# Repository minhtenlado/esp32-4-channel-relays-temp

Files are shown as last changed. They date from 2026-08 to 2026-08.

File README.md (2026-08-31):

<div align="center">

# ⚡ Mạch Điều Khiển 4 Relay Cách Ly Quang Dùng ESP32 (KiCad)

Dự án thiết kế phần cứng mã nguồn mở **Mạch Điều Khiển 4 Kênh Relay sử dụng vi điều khiển ESP32-WROOM-32**, thiết kế trên phần mềm **KiCad**. Mạch tích hợp cách ly quang toàn phần (Optocoupler), cổng nạp USB Type-C tự động reset (Auto-Download), bảo vệ chống tĩnh điện ESD, cầu chì tự phục hồi PTC và rãnh cách ly an toàn điện áp cao (Creepage Slots) chuyên dụng cho nhà thông minh (Smart Home) và tự động hóa công nghiệp (IoT).







<br/>

[📖 English Version](README_EN.md) • [📑 Xem Sơ Đồ Nguyên Lý PDF](schematic.pdf) • [📊 Danh Mục Linh Kiện (BOM)](docs/BOM.md) • [📌 Sơ Đồ Chân (Pinout)](docs/PINOUT.md)

<br/>

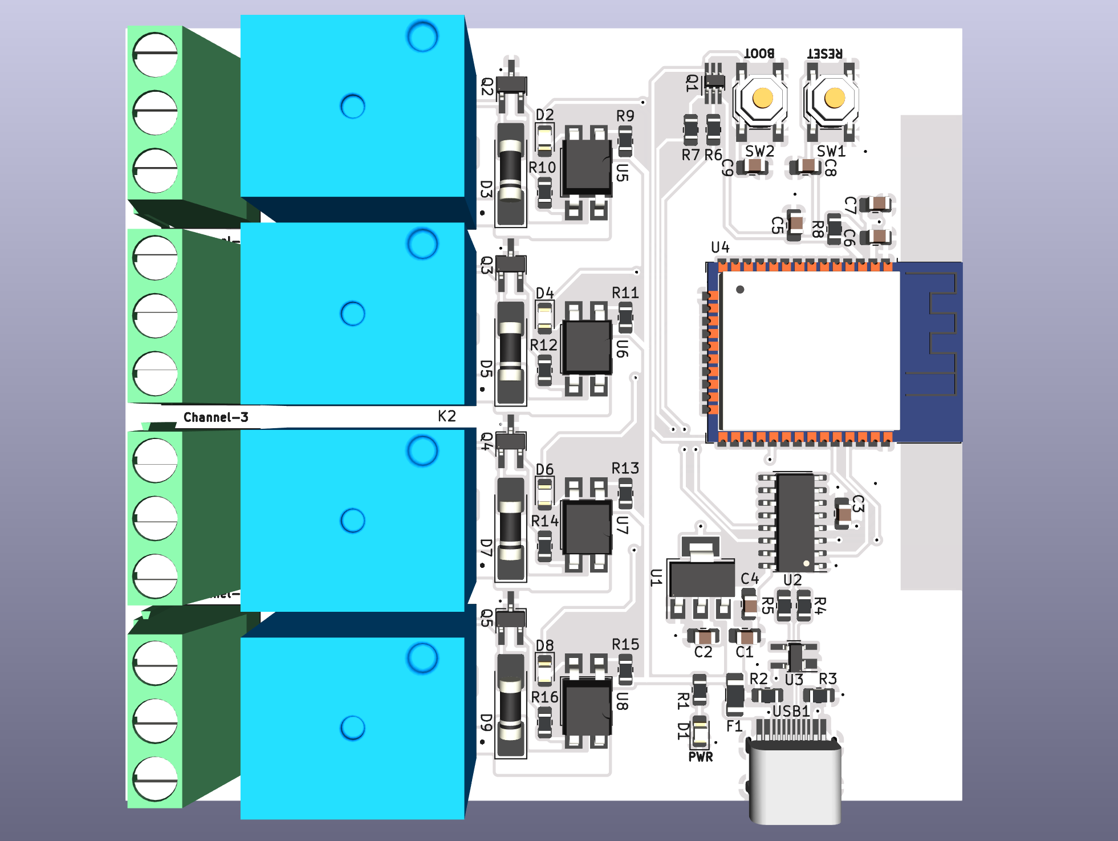
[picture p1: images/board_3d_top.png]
Phối cảnh 3D Mạch Điều Khiển 4 Relay ESP32


</div>

---

## 🌟 Điểm Nổi Bật Của Thiết Kế

- 🧠 **Vi điều khiển lõi kép ESP32**: ESP32-WROOM-32 tích hợp kết nối Wi-Fi 2.4 GHz và Bluetooth LE 4.2 tốc độ cao.
- 🔌 **4 Kênh Relay độc lập**: Sử dụng Relay Songle SRD-05VDC-SL-C cho khả năng đóng cắt dòng tải lên đến **10A @ 250VAC / 10A @ 30VDC**.
- 🛡️ **Cách ly quang an toàn (Galvanic Opto-Isolation)**: Sử dụng 4 Optocoupler PC817 cách ly hoàn toàn khối vi điều khiển 3.3V với khối cuộn hút Relay 5V, chống nhiễu xung ngược khi đóng ngắt.
- ⚡ **Cổng giao tiếp USB Type-C hiện đại**: Cổng Type-C (HRO-TYPE-C-31-M-12) vừa cấp nguồn 5V vừa nạp code trực tiếp từ máy tính.
- 🔄 **Mạch tự động nạp & reset (Auto-Download)**: Tích hợp chip chuyển đổi USB-UART CH340C cùng cặp transistor MBT3904DW1 điều khiển chân `EN` và `IO0` (tự động vào chế độ nạp không cần nhấn nút thủ công).
- 🔒 **Hệ thống bảo vệ phần cứng đa lớp**:
  - Cầu chì tự phục hồi PTC 500mA (`F1`) bảo vệ quá dòng cổng USB.
  - Mảng Diode TVS PRTR5V0U2X (`U3`) triệt tiêu xung tĩnh điện ESD trên đường tín hiệu USB D+/D-.
  - Diode dập xung ngược 1N4007 (`D3, D5, D7, D9`) bảo vệ transistor khi ngắt cuộn dây relay.
  - Phay rãnh cách ly điện áp cao (Isolation Creepage Slots) giữa tiếp điểm Relay và mạch điều khiển.
- 💡 **Đèn LED hiển thị trực quan**:
  - 1 LED Vàng báo nguồn 3.3V (`D1`).
  - 4 LED Đỏ báo trạng thái kích hoạt của từng Relay (`D2, D4, D6, D8`).
- 📶 **Thiết kế anten RF tối ưu**: Khu vực Anten PCB của ESP32 được bố trí nhô ra ngoài với vùng cấm đi dây (Keep-out Zone) để tăng tối đa khoảng cách thu phát sóng Wi-Fi.

---

## 📸 Hình Ảnh Phối Cảnh & Layout PCB

<div align="center">
  <table>
    <tr>
      <td align="center"><b>Phối cảnh 3D Mặt Trước (Top View)</b></td>
      <td align="center"><b>Phối cảnh 3D Mặt Sau (Bottom View)</b></td>
    </tr>
    <tr>
      <td>Mặt trước 3D</td>
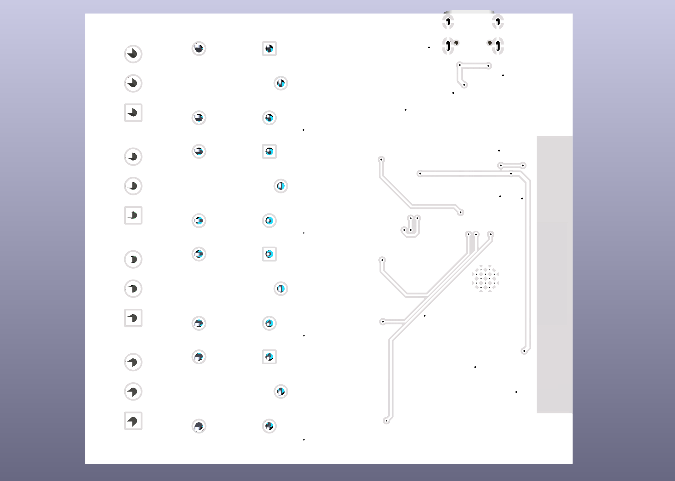
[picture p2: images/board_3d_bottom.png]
Mặt sau 3D
      <td></td>
    </tr>
    <tr>
      <td colspan="2" align="center"><b>Bản Vẽ Thiết Kế Layout 2D (KiCad PCB)</b></td>
    </tr>
    <tr>
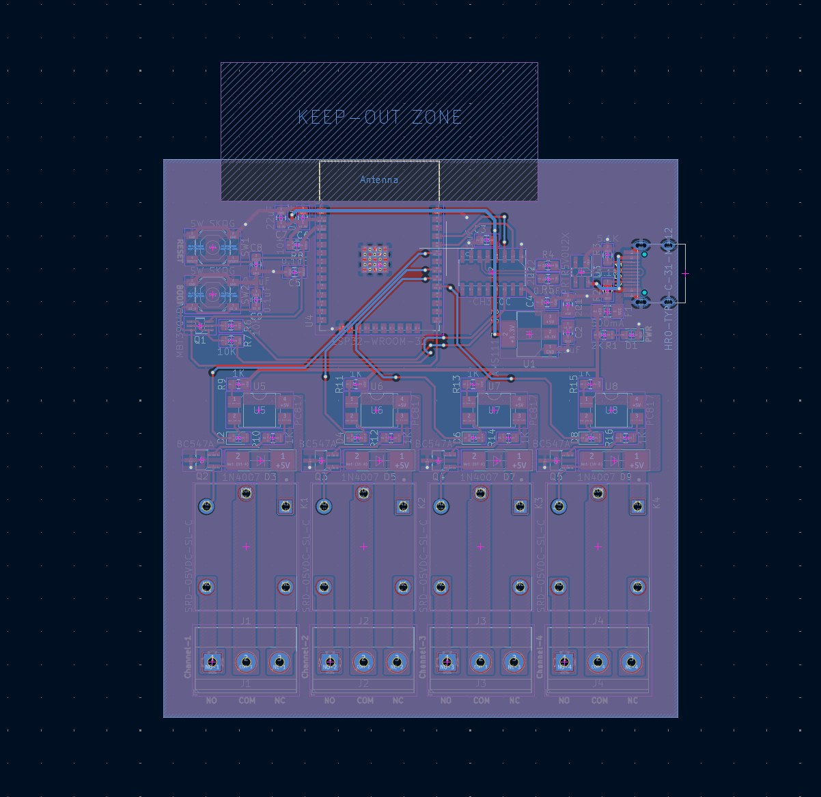
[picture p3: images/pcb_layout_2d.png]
PCB Layout 2D
      <td colspan="2" align="center"></td>
    </tr>
  </table>
</div>

---

## 📋 Thông Số Kỹ Thuật Chi Tiết

| Thông số | Giá trị chi tiết |
| :--- | :--- |
| **Vi điều khiển chính** | ESP32-WROOM-32 (Xtensa Dual-Core 32-bit LX6, tần số tối đa 240 MHz) |
| **Nguồn cấp đầu vào** | 5V DC qua cổng USB Type-C |
| **Điện áp hoạt động Logic** | 3.3V DC (Hạ áp qua IC AMS1117-3.3V dòng tối đa 1A) |
| **Số kênh Relay** | 4 Kênh độc lập (Tiếp điểm SPDT: NO - Thường mở, COM - Chung, NC - Thường đóng) |
| **Loại Relay** | Songle SRD-05VDC-SL-C (Cuộn hút 5V DC) |
| **Công suất tiếp điểm (AC)**| 10A 250VAC / 10A 125VAC |
| **Công suất tiếp điểm (DC)**| 10A 30VDC / 10A 28VDC |
| **Cổng kết nối tải** | 4 Domino (Terminal Block) 3 chân, bước chân chuẩn 5.08mm |
| **Cơ chế cách ly** | Optocoupler quang PC817 + Rãnh cách ly phay cơ khí trên mạch |
| **Chip nạp USB-UART** | CH340C (Tích hợp sẵn thạch anh nội dao động) |
| **Nền tảng lập trình hỗ trợ** | Arduino IDE, PlatformIO, ESP-IDF, ESPHome (Home Assistant), Tasmota |

---

## 📌 Sơ Đồ Chân (Pinout & GPIO Mapping)

| Kênh chức năng | Chân ESP32 | Mức kích hoạt | Opto cách ly | Transistor kích | LED Trạng thái | Cổng Domino ra tải |
| :--- | :---: | :---: | :---: | :---: | :---: | :--- |
| **Relay 1** | `GPIO 21` | Mức CAO (`HIGH`) | U5 (PC817) | Q2 (BC547A) | `D2` (LED Đỏ) | **J1** (NO, COM, NC) |
| **Relay 2** | `GPIO 19` | Mức CAO (`HIGH`) | U6 (PC817) | Q3 (BC547A) | `D4` (LED Đỏ) | **J2** (NO, COM, NC) |
| **Relay 3** | `GPIO 18` | Mức CAO (`HIGH`) | U7 (PC817) | Q4 (BC547A) | `D6` (LED Đỏ) | **J3** (NO, COM, NC) |
| **Relay 4** | `GPIO 5`  | Mức CAO (`HIGH`) | U8 (PC817) | Q5 (BC547A) | `D8` (LED Đỏ) | **J4** (NO, COM, NC) |
| **UART RX**  | `GPIO 3`  | - | - | - | Chân TX CH340C | Cổng nạp USB Type-C |
| **UART TX**  | `GPIO 1`  | - | - | - | Chân RX CH340C | Cổng nạp USB Type-C |
| **Nút BOOT** | `GPIO 0`  | Mức THẤP (`LOW`) | - | - | Nút nhấn `SW2` | Vào chế độ nạp thủ công |
| **Nút RESET**| `EN` | Mức THẤP (`LOW`) | - | - | Nút nhấn `SW1` | Reset phần cứng |
| **LED Nguồn**| `+3.3V` | Sáng liên tục | - | - | `D1` (LED Vàng) | Báo nguồn 3.3V ổn định |

👉 Xem hướng dẫn phân tích phần cứng và chân strapping chi tiết tại: [docs/PINOUT.md](docs/PINOUT.md).

---

## 🗂️ Cấu Trúc Thư Mục Dự Án

```text
.
├── esp32-4-channel-relays.kicad_pro   # File Project KiCad (v7 / v8 / v10)
├── esp32-4-channel-relays.kicad_sch   # File Sơ đồ nguyên lý (Schematic)
├── esp32-4-channel-relays.kicad_pcb   # File Thiết kế mạch in (PCB Layout)
├── schematic.pdf                      # Bản xuất sơ đồ nguyên lý định dạng PDF
├── images/                            # Ảnh render 3D và sơ đồ layout PCB
│   ├── board_3d_top.png               # Phối cảnh 3D mặt trước
│   ├── board_3d_bottom.png            # Phối cảnh 3D mặt sau
│   └── pcb_layout_2d.png              # Bản vẽ layout PCB 2D
├── lib/                               # Thư viện linh kiện KiCad riêng của dự án
│   ├── 3dmodel/                       # Mô hình 3D CAD (.step, .wrl)
│   ├── footprint/                     # Thư viện Footprint chân linh kiện (.kicad_mod)
│   └── symbol/                        # Thư viện Symbol ký hiệu nguyên lý (.kicad_sym)
├── docs/                              # Tài liệu kỹ thuật dự án
│   ├── BOM.md                         # Bảng danh mục linh kiện (Markdown)
│   ├── BOM.csv                        # Danh mục linh kiện (File CSV)
│   └── PINOUT.md                      # Bảng tra cứu sơ đồ chân phần cứng
├── firmware/                          # Mã nguồn mẫu sẵn sàng nạp
│   ├── arduino/esp32_4ch_relay_web/   # Code Arduino Web Server + REST API điều khiển Relay
│   └── esphome/esp32_4ch_relay.yaml   # Cấu hình ESPHome nạp vào Home Assistant
├── .github/                           # GitHub Actions CI kiểm tra file & mẫu Issue
├── .gitignore                         # Bộ lọc file rác, file tạm của KiCad
├── CONTRIBUTING.md                    # Hướng dẫn đóng góp phát triển dự án
├── LICENSE                            # Giấy phép mã nguồn mở CERN-OHL-P v2 & MIT
├── README_EN.md                       # Tài liệu tiếng Anh (English documentation)
└── README.md                          # Tài liệu hướng dẫn chính (Tiếng Việt)
```

---

## 🚀 Hướng Dẫn Nạp Firmware & Sử Dụng

### 1. Điều khiển qua Web & Serial bằng Arduino IDE
Mã nguồn mẫu hoàn chỉnh có sẵn tại thư mục [`firmware/arduino/esp32_4ch_relay_web/`](firmware/arduino/esp32_4ch_relay_web/esp32_4ch_relay_web.ino).

1. Cài đặt **Arduino IDE** và cài board **ESP32 by Espressif**.
2. Mở file `esp32_4ch_relay_web.ino`.
3. Điền thông tin Wi-Fi nhà bạn:
   ```cpp
   const char* WIFI_SSID = "TEN_WIFI_CUA_BAN";
   const char* WIFI_PASS = "MAT_KHAU_WIFI";
   ```
4. Cắm cáp USB Type-C từ máy tính vào mạch, chọn cổng COM và bấm **Upload** (Mạch có tính năng tự động nạp code không cần giữ nút BOOT).
5. Mở trình duyệt web truy cập vào: `http://esp32-relay.local` hoặc địa chỉ IP hiển thị trên Serial Monitor để điều khiển bật/tắt 4 relay.

### 2. Tích hợp trực tiếp vào Home Assistant qua ESPHome
Dự án đã chuẩn bị sẵn file cấu hình [`firmware/esphome/esp32_4ch_relay.yaml`](firmware/esphome/esp32_4ch_relay.yaml).

1. Cài đặt [ESPHome](https://esphome.io/) trên máy tính hoặc Add-on trong Home Assistant.
2. Nạp file cấu hình qua USB bằng lệnh:
   ```bash
   esphome run firmware/esphome/esp32_4ch_relay.yaml
   ```
3. Sau khi nạp xong, Home Assistant sẽ tự động nhận diện thiết bị và tạo sẵn 4 công tắc tương ứng với 4 kênh relay.

---

## ⚠️ Cảnh Báo An Toàn Điện Áp Cao (220V AC)

> [!WARNING]
> **CẢNH BÁO AN TOÀN ĐIỆN NGUY HIỂM**: Đóng cắt điện lưới xoay chiều 220V AC tiềm ẩn nguy cơ giật điện và hỏa hoạn nghiêm trọng.
> - Luôn ngắt toàn bộ nguồn điện trước khi đấu nối dây điện vào cọc Domino (Terminal Block).
> - Khi đóng cắt tải điện 220V, bắt buộc phải đặt mạch trong hộp bảo vệ cách điện (nhựa chống cháy, in 3D kín).
> - Đảm bảo dòng điện tải thực tế không vượt quá định mức của tiếp điểm Relay và đường mạch đồng.

---

## 📦 Danh Mục Linh Kiện (BOM)

Toàn bộ thông tin chi tiết về linh kiện (Package SMD 0805 dễ hàn tay, chân cắm THT, mã IC):
- 📄 [Xem Bảng Tra Linh Kiện BOM (Markdown)](docs/BOM.md)
- 📊 [Tải File Excel/CSV BOM (docs/BOM.csv)](docs/BOM.csv)
- 📑 [Xem Bản Vẽ Sơ Đồ Nguyên Lý PDF](schematic.pdf)

---

## 📄 Bản Quyền & Tác Giả

- **Thiết kế phần cứng**: Cấp phép theo chuẩn phần cứng mở **[CERN-OHL-P v2](https://cern-ohl.web.cern.ch/)** (CERN Open Hardware Licence Version 2 - Permissive).
- **Mã nguồn phần mềm & Tài liệu**: Cấp phép theo chuẩn **[MIT License](LICENSE)**.
- **Tác giả thiết kế**: **Phan Huỳnh Văn Đô** (`2023 - 2026`).

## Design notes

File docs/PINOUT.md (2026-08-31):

# Sơ Đồ Chân (Pinout) & Cấu Trúc Phần Cứng ESP32 4-Channel Relays

## 1. Bảng Ánh Xạ Chân Điều Khiển 4 Kênh Relay

Vi điều khiển ESP32 điều khiển từng kênh relay thông qua tầng cách ly quang Optocoupler và transistor đệm dòng.

| Kênh | Chân ESP32 | Optocoupler | Transistor kích | LED Trạng thái | Diode dập xung | Cổng kết nối (Domino) | Mức kích hoạt |
| :--- | :--- | :--- | :--- | :--- | :--- | :--- | :--- |
| **Relay 1** | `GPIO 21` | U5 (PC817) | Q2 (BC547A) | D2 (Đỏ) | D3 (1N4007) | J1 (NO, COM, NC) | Mức CAO (`HIGH`) |
| **Relay 2** | `GPIO 19` | U6 (PC817) | Q3 (BC547A) | D4 (Đỏ) | D5 (1N4007) | J2 (NO, COM, NC) | Mức CAO (`HIGH`) |
| **Relay 3** | `GPIO 18` | U7 (PC817) | Q4 (BC547A) | D6 (Đỏ) | D7 (1N4007) | J3 (NO, COM, NC) | Mức CAO (`HIGH`) |
| **Relay 4** | `GPIO 5`  | U8 (PC817) | Q5 (BC547A) | D8 (Đỏ) | D9 (1N4007) | J4 (NO, COM, NC) | Mức CAO (`HIGH`) |

*Ghi chú*: Mạch được thiết kế kích ở **Mức CAO** (Xuất tín hiệu `HIGH` sẽ làm sáng LED bên trong Optocoupler, kích dẫn Transistor BC547A đóng cuộn hút Relay và làm sáng LED đỏ báo hiệu).

---

## 2. Ý Nghĩa Các Tiếp Điểm Trên Cọc Đấu Nối Domino (5.08mm)

Mỗi kênh Relay đi ra 1 cọc domino 3 chân có nhãn:
- **NO (Normally Open - Thường mở)**: Tiếp điểm hở mạch khi relay chưa được kích hoạt, đóng mạch khi relay có điện.
- **COM (Common - Chân chung)**: Chân chung để đấu nguồn điện cấp cho tải.
- **NC (Normally Closed - Thường đóng)**: Tiếp điểm đóng mạch khi relay chưa được kích hoạt, hở mạch khi relay có điện.

---

## 3. Kiến Trúc Cung Cấp Nguồn Điện

| Đường nguồn | Nguồn cấp vào | IC điều chỉnh | Dòng tối đa | Mục đích sử dụng |
| :--- | :--- | :--- | :--- | :--- |
| **+5V (VBUS)** | Cổng USB Type-C | Qua cầu chì F1 (500mA PTC) | ~500mA - 1A | Cấp nguồn cuộn hút 4 Relay (SRD-05VDC-SL-C) |
| **+3.3V** | Từ đường 5V | IC Hạ áp AMS1117-3.3 (U1) | 1A | Cấp nguồn cho ESP32-WROOM-32, IC nạp CH340C |
| **GND** | Cổng USB Type-C | Mặt phẳng GND chung | - | Mass toàn hệ thống |

---

## 4. Mạch Tự Động Nạp (Auto-Download) & Nút Nhấn

| Tín hiệu / Linh kiện | Chân ESP32 | Chức năng |
| :--- | :--- | :--- |
| **TXD (CH340C TX)** | `GPIO 3` (RXD0) | Nhận dữ liệu UART0 từ máy tính vào ESP32 |
| **RXD (CH340C RX)** | `GPIO 1` (TXD0) | Truyền dữ liệu UART0 từ ESP32 lên máy tính |
| **DTR / RTS** | `EN` / `GPIO 0` | Tín hiệu tự động reset / vào bootloader qua Q1 (MBT3904DW1) |
| **Nút SW1 (RESET)** | `EN` (CHIP_PU) | Nút reset phần cứng (Mức THẤP, có trở kéo 10k và tụ lọc nhiễu 0.1uF) |
| **Nút SW2 (BOOT)** | `GPIO 0` | Nút kích hoạt chế độ Bootloader thủ công (Mức THẤP, có trở kéo 10k) |

---

## 5. Bảng Chân Cấu Hình Khởi Động ESP32 (Strapping Pins)

| Chân GPIO | Trạng thái mặc định | Kết nối trên mạch | Lưu ý khi lập trình |
| :--- | :--- | :--- | :--- |
| `GPIO 0` | Kéo lên (+3.3V qua 10k) | Nối nút SW2 / Mạch nạp Q1 | Kéo xuống LOW lúc khởi động để vào chế độ nạp ROM |
| `GPIO 2` | Kéo xuống LOW nội | Bỏ trống | Giữ ở mức LOW hoặc thả nổi khi nạp firmware |
| `GPIO 5` | Mức CAO lúc boot | **Kích Relay 4** | Có xung phát ra lúc ESP32 vừa bật nguồn, hoạt động bình thường |
| `GPIO 12` | Kéo xuống LOW (MTDI) | Bỏ trống | Chọn điện áp Flash 3.3V |
| `GPIO 15` | Mức CAO (MTDO) | Bỏ trống | Bật/tắt chế độ in log bootloader qua UART |

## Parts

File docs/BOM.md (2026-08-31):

# Bảng Danh Mục Linh Kiện (BOM) - Mạch Điều Khiển 4 Relay ESP32

Danh mục linh kiện đầy đủ cho mạch điều khiển 4 Relay cách ly quang ESP32-WROOM-32.

| STT | Số lượng | Ký hiệu (Designator) | Giá trị / Tên linh kiện | Đóng gói (Footprint) | Chức năng / Mô tả chi tiết |
| :---: | :---: | :--- | :--- | :--- | :--- |
| 1 | 1 | `U4` | ESP32-WROOM-32 | Module SMD | Vi điều khiển 32-bit Wi-Fi & Bluetooth Dual-Core |
| 2 | 4 | `K1, K2, K3, K4` | SRD-05VDC-SL-C | THT Relay | Relay 5VDC SPDT (Đóng ngắt 10A 250VAC / 10A 30VDC) |
| 3 | 4 | `U5, U6, U7, U8` | PC817 | SMDIP-4 | Optocoupler cách ly quang bảo vệ vi điều khiển |
| 4 | 4 | `Q2, Q3, Q4, Q5` | BC547A / NPN | SOT-23 | Transistor NPN đóng ngắt cuộn hút 5V của Relay |
| 5 | 4 | `D3, D5, D7, D9` | 1N4007 | MELF / DO-213AB | Diode dập xung điện áp ngược khi ngắt cuộn dây (1A 1000V) |
| 6 | 4 | `D2, D4, D6, D8` | LED Đỏ | 0805 SMD | Đèn LED hiển thị trạng thái kích hoạt Kênh 1 - 4 |
| 7 | 1 | `D1` | LED Vàng | 0805 SMD | Đèn LED báo nguồn 3.3V của mạch |
| 8 | 4 | `J1, J2, J3, J4` | Domino 3 Chân (Terminal) | Bước chân 5.08mm | Cọc đấu nối ra tải điện (NO - Thường mở, COM - Chung, NC - Thường đóng) |
| 9 | 1 | `USB1` | Type-C 16-Pin | HRO-TYPE-C-31-M-12 | Cổng USB Type-C cấp nguồn 5V và nạp dữ liệu |
| 10 | 1 | `U2` | CH340C | SOIC-16 | IC chuyển đổi USB sang UART tích hợp sẵn dao động thạch anh |
| 11 | 1 | `Q1` | MBT3904DW1 | SOT-363 / SC-70-6 | Cặp transistor NPN kép trong mạch tự động nạp & reset |
| 12 | 1 | `U1` | AMS1117-3.3 | SOT-223-3 | IC ổn áp tuyến tính 3.3V 1A cấp nguồn cho ESP32 |
| 13 | 1 | `U3` | PRTR5V0U2X | SOT-143 | Diode TVS chống tĩnh điện ESD cho 2 đường dữ liệu USB |
| 14 | 1 | `F1` | Cầu chì PTC 500mA | 1206 SMD | Cầu chì tự phục hồi chống quá dòng cổng USB |
| 15 | 2 | `SW1, SW2` | Nút nhấn nhả (Tactile) | SKQG SMD 6x6mm | Nút bấm RESET (SW1) và nút BOOT (SW2) |
| 16 | 8 | `R9, R10, R11, R12, R13, R14, R15, R16` | 1kΩ 1% | 0805 SMD | Điện trở hạn dòng cho LED opto và phân cực cực B transistor |
| 17 | 3 | `R6, R7, R8` | 10kΩ 1% | 0805 SMD | Điện trở kéo lên (Pull-up) cho chân EN, IO0 và BOOT |
| 18 | 2 | `R2, R3` | 5.1kΩ 1% | 0805 SMD | Điện trở kéo xuống cấu hình nhận diện cổng USB Type-C (CC1, CC2) |
| 19 | 2 | `R4, R5` | 22Ω 1% | 0805 SMD | Điện trở phối hợp trở kháng trên đường dữ liệu USB D+ / D- |
| 20 | 1 | `R1` | 2kΩ 1% | 0805 SMD | Điện trở hạn dòng cho đèn LED báo nguồn D1 |
| 21 | 3 | `C1, C2, C7` | 22µF 16V | 0805 SMD | Tụ gốm lọc nguồn chính đường 5V và 3.3V |
| 22 | 6 | `C3, C4, C5, C6, C8, C9` | 0.1µF (100nF) 50V | 0805 SMD | Tụ gốm lọc nhiễu cao tần (Decoupling) |

> **Ghi chú**: Các điện trở và tụ điện SMD sử dụng chuẩn chân **0805** giúp việc hàn thủ công bằng mỏ hàn tay dễ dàng và đẹp mắt.

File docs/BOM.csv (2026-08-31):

Item | Qty | Reference | Value | Footprint | Description
1 | 1 | U4 | ESP32-WROOM-32 | Module SMD | Wi-Fi & Bluetooth Dual-Core MCU Module
2 | 4 | K1, K2, K3, K4 | SRD-05VDC-SL-C | THT Relay | 5VDC SPDT Relay (10A 250VAC / 10A 30VDC)
3 | 4 | U5, U6, U7, U8 | PC817 | SMDIP-4 | Optocoupler Phototransistor Galvanic Isolator
4 | 4 | Q2, Q3, Q4, Q5 | BC547A / NPN | SOT-23 | NPN General Purpose Transistor (Relay Coil Driver)
5 | 4 | D3, D5, D7, D9 | 1N4007 | MELF / DO-213AB | 1A 1000V General Purpose Flyback Diode
6 | 4 | D2, D4, D6, D8 | RED LED | 0805 SMD | Relay Channel 1-4 Active Status Indicator
7 | 1 | D1 | YELLOW LED | 0805 SMD | 3.3V Power Rail Indicator
8 | 4 | J1, J2, J3, J4 | Screw Terminal 3-Pin | 5.08mm Pitch | Screw Terminal (NO, COM, NC Contacts)
9 | 1 | USB1 | Type-C 16-Pin | HRO-TYPE-C-31-M-12 | USB Type-C Receptacle 5V Power & Data
10 | 1 | U2 | CH340C | SOIC-16 | USB to Serial UART Interface with Built-in Oscillator
11 | 1 | Q1 | MBT3904DW1 | SOT-363 / SC-70-6 | Dual NPN Transistor Auto-Reset & Download Circuit
12 | 1 | U1 | AMS1117-3.3 | SOT-223-3 | 3.3V 1A Low Dropout Linear Voltage Regulator
13 | 1 | U3 | PRTR5V0U2X | SOT-143 | Ultra-low Capacitance TVS Diode ESD Protection
14 | 1 | F1 | 500mA PTC | 1206 SMD | Resettable Polyfuse Overcurrent Protection
15 | 2 | SW1, SW2 | Tactile Button | SKQG / 6x6mm SMD | Tactile Switches (RESET / BOOT)
16 | 8 | R9, R10, R11, R12, R13, R14, R15, R16 | 1kΩ 1% | 0805 SMD | Optocoupler LED Current Limiting & Base Drive Resistors
17 | 3 | R6, R7, R8 | 10kΩ 1% | 0805 SMD | Pull-Up Resistors (EN / IO0 / BOOT)
18 | 2 | R2, R3 | 5.1kΩ 1% | 0805 SMD | USB Type-C CC1 / CC2 Pull-Down Resistors
19 | 2 | R4, R5 | 22Ω 1% | 0805 SMD | USB D+ / D- Series Termination Resistors
20 | 1 | R1 | 2kΩ 1% | 0805 SMD | Power LED Current Limiting Resistor
21 | 3 | C1, C2, C7 | 22µF 16V | 0805 SMD | Bulk Filtering Capacitors (5V / 3.3V rails)
22 | 6 | C3, C4, C5, C6, C8, C9 | 0.1µF (100nF) 50V | 0805 SMD | Decoupling Ceramic Capacitors

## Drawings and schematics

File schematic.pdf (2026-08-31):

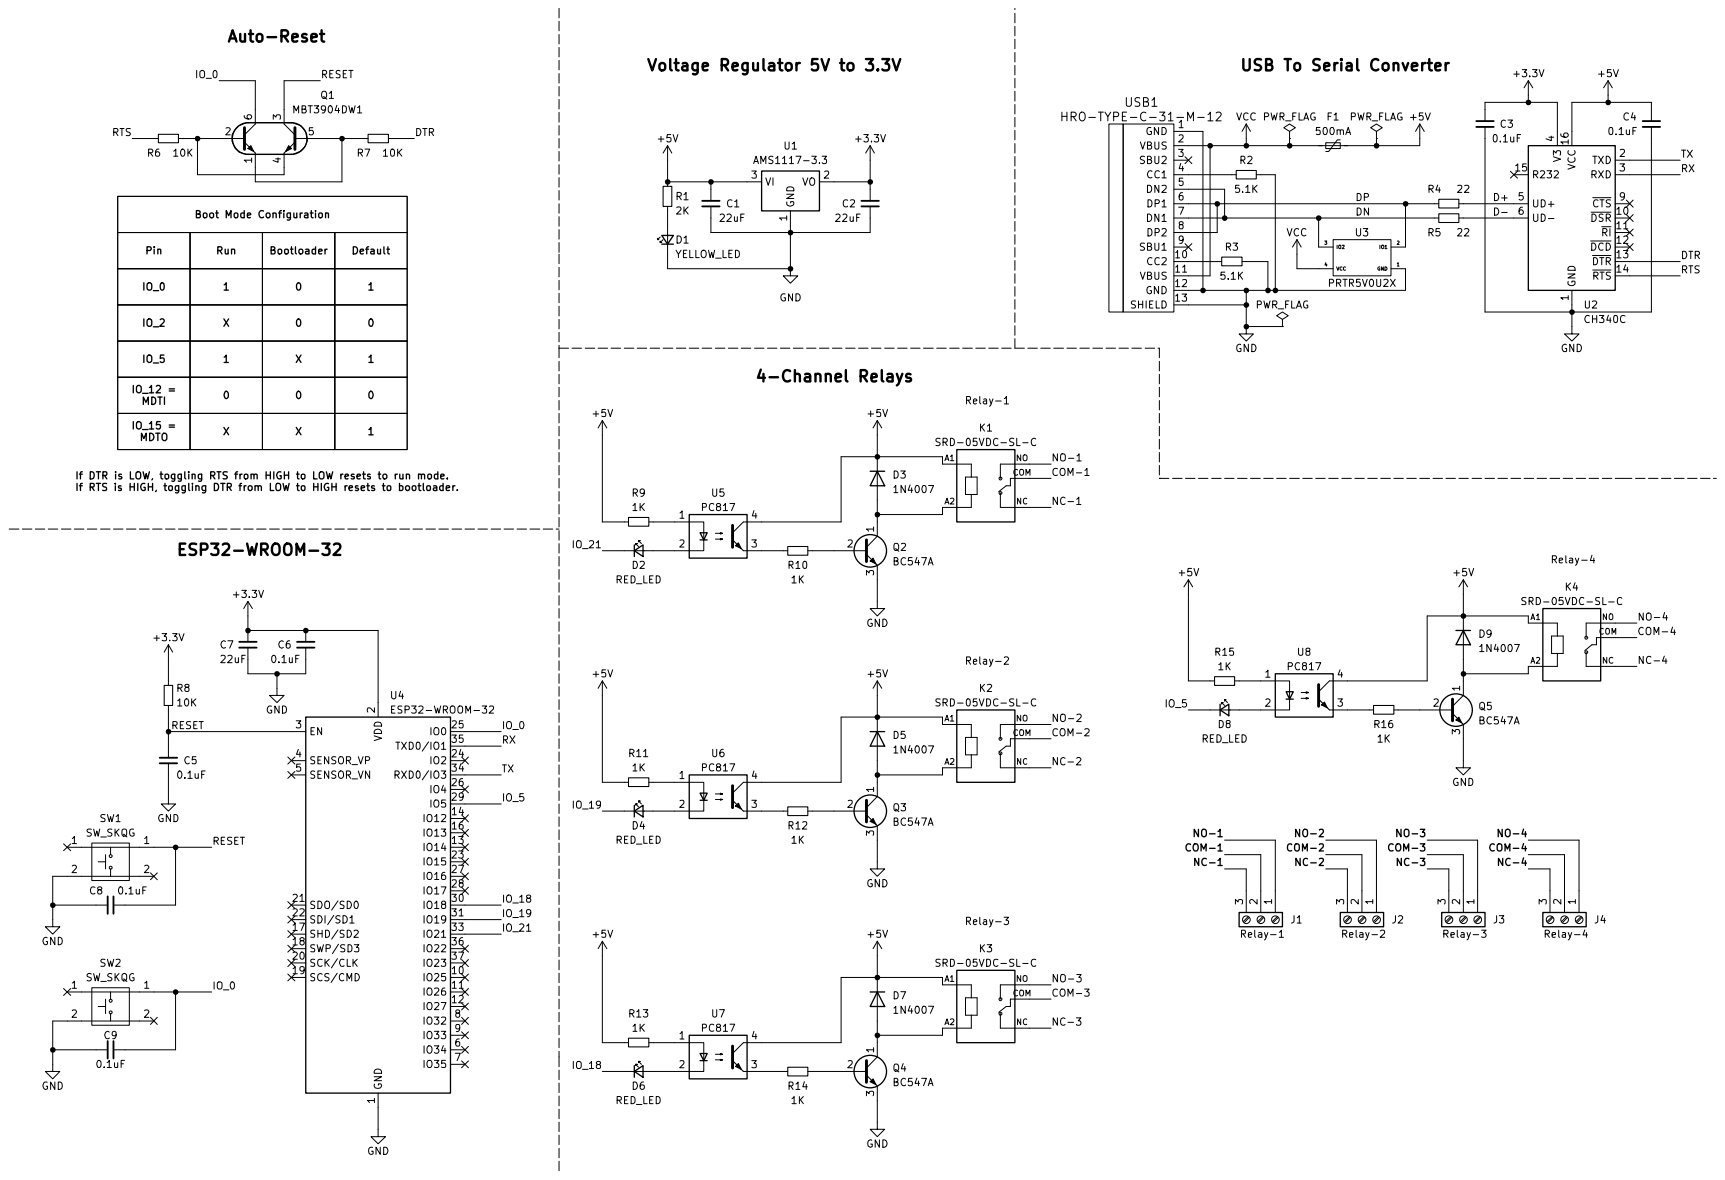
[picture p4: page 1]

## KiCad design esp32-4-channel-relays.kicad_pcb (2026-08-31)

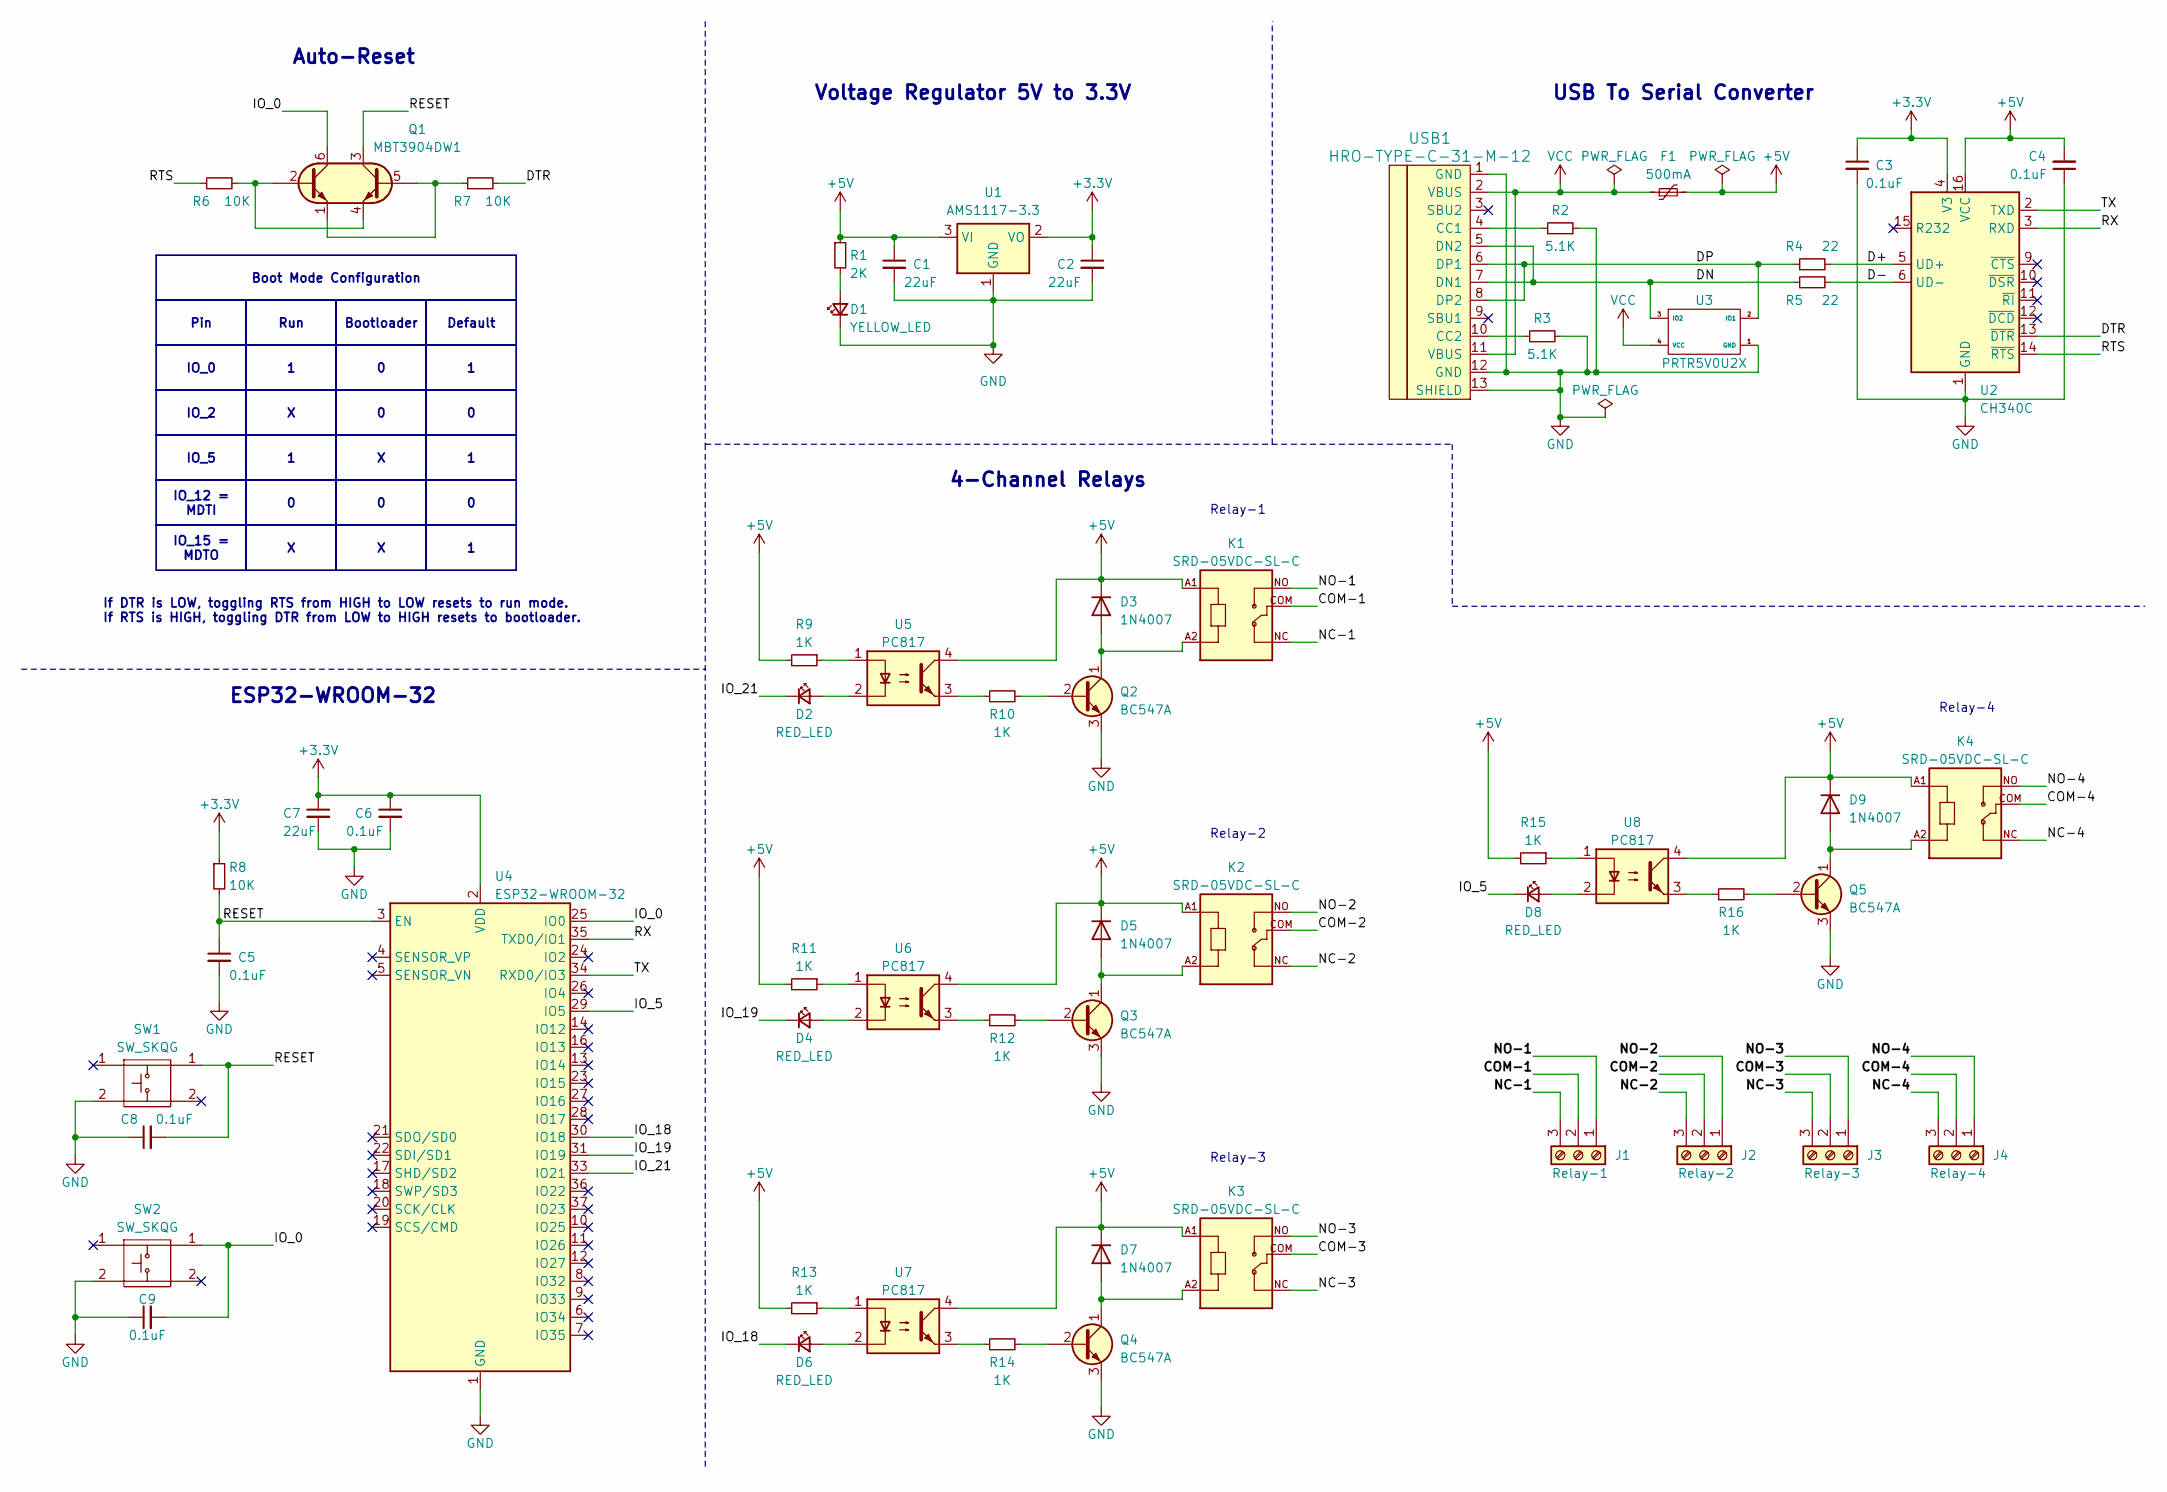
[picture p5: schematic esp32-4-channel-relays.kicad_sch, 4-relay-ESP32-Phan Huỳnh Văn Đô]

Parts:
C1, C2, C7: 22uF; C_0805_2012Metric_Pad1.18x1.45mm_HandSolder
C3, C4, C5, C6, C8, C9: 0.1uF; C_0805_2012Metric_Pad1.18x1.45mm_HandSolder
D1: YELLOW_LED; LED_0805_2012Metric_Pad1.15x1.40mm_HandSolder
D2, D4, D6, D8: RED_LED; LED_0805_2012Metric_Pad1.15x1.40mm_HandSolder
D3, D5, D7, D9: 1N4007; D_MELF_Handsoldering
F1: 500mA; Fuse_1206_3216Metric_Pad1.42x1.75mm_HandSolder
J1: Relay-1; TerminalBlock_Phoenix_MKDS-1,5-3-5.08_1x03_P5.08mm_Horizont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
J2: Relay-2; TerminalBlock_Phoenix_MKDS-1,5-3-5.08_1x03_P5.08mm_Horizont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
J3: Relay-3; TerminalBlock_Phoenix_MKDS-1,5-3-5.08_1x03_P5.08mm_Horizont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
J4: Relay-4; TerminalBlock_Phoenix_MKDS-1,5-3-5.08_1x03_P5.08mm_Horizont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
K1, K2, K3, K4: SRD-05VDC-SL-C; RELAY_SRD-05VDC-SL-C
Q1: MBT3904DW1; SOT-363_SC-70-6_Handsoldering
Q2, Q3, Q4, Q5: BC547A; TSOT-23_HandSoldering
R1: 2K; R_0805_2012Metric_Pad1.20x1.40mm_HandSolder
R2, R3: 5.1K; R_0805_2012Metric_Pad1.20x1.40mm_HandSolder
R4, R5: 22; R_0805_2012Metric_Pad1.20x1.40mm_HandSolder
R6, R7, R8: 10K; R_0805_2012Metric_Pad1.20x1.40mm_HandSolder
R9, R10, R11, R12, R13, R14, R15, R16: 1K; R_0805_2012Metric_Pad1.20x1.40mm_HandSolder
SW1, SW2: SW_SKQG; SW_SPST_SKQG_WithStem
U1: AMS1117-3.3; SOT-223-3_TabPin2
U2: CH340C; SOIC-16_3.9x9.9mm_P1.27mm
U3: PRTR5V0U2X; SOT-143_Handsoldering
U4: ESP32-WROOM-32
U5, U6, U7, U8: PC817; SMDIP-4_W7.62mm
USB1: HRO-TYPE-C-31-M-12; HRO-TYPE-C-31-M-12-HandSoldering

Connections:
+3.3V: C2.1, C3.1, C6.1, C7.1, R8.1, U1.2 (VO), U2.4 (V3), U4.2 (VDD)
+5V: C1.1, C4.2, D3.1 (K), D5.1 (K), D7.1 (K), D9.1 (K), F1.2, K1.A1, K2.A1, K3.A1, K4.A1, R1.1, R9.2, R11.2, R13.2, R15.2, U1.3 (VI), U2.16 (VCC), U5.4, U6.4, U7.4, U8.4
/COM-1: J1.2, K1.COM
/COM-2: J2.2, K2.COM
/COM-3: J3.2, K3.COM
/COM-4: J4.2, K4.COM
/D+: R4.2, U2.5 (UD+)
/D-: R5.2, U2.6 (UD-)
/DN: R5.1, U3.3 (IO2), USB1.5 (DN2), USB1.7 (DN1)
/DP: R4.1, U3.2 (IO1), USB1.6 (DP1), USB1.8 (DP2)
/DTR: R7.2, U2.13 (~DTR)
/IO_0: C9.2, Q1.6 (C1), SW2.1, U4.25 (IO0)
/IO_5: D8.1 (K), U4.29 (IO5)
/IO_18: D6.1 (K), U4.30 (IO18)
/IO_19: D4.1 (K), U4.31 (IO19)
/IO_21: D2.1 (K), U4.33 (IO21)
/NC-1: J1.3, K1.NC
/NC-2: J2.3, K2.NC
/NC-3: J3.3, K3.NC
/NC-4: J4.3, K4.NC
/NO-1: J1.1, K1.NO
/NO-2: J2.1, K2.NO
/NO-3: J3.1, K3.NO
/NO-4: J4.1, K4.NO
/RESET: C5.1, C8.2, Q1.3 (C2), R8.2, SW1.1, U4.3 (EN)
/RTS: R6.1, U2.14 (~RTS)
/RX: U2.3 (RXD), U4.35 (TXD0/IO1)
/TX: U2.2 (TXD), U4.34 (RXD0/IO3)
GND: C1.2, C2.2, C3.2, C4.1, C5.2, C6.2, C7.2, C8.1, C9.1, D1.1 (K), Q2.3 (E), Q3.3 (E), Q4.3 (E), Q5.3 (E), R2.2, R3.2, SW1.2, SW2.2, U1.1 (GND), U2.1 (GND), U3.1 (GND), U4.1 (GND), U4.15 (GND), U4.38 (GND), U4.39 (GND), USB1.1 (GND), USB1.12 (GND), USB1.13 (SHIELD)
unnamed: D1.2 (A), R1.2
unnamed: D2.2 (A), U5.2
unnamed: D3.2 (A), K1.A2, Q2.1 (C)
unnamed: D4.2 (A), U6.2
unnamed: D5.2 (A), K2.A2, Q3.1 (C)
unnamed: D6.2 (A), U7.2
unnamed: D7.2 (A), K3.A2, Q4.1 (C)
unnamed: D8.2 (A), U8.2
unnamed: D9.2 (A), K4.A2, Q5.1 (C)
unnamed: Q1.2 (B1), Q1.4 (E2), R6.2
unnamed: Q1.1 (E1), Q1.5 (B2), R7.1
unnamed: Q2.2 (B), R10.2
unnamed: Q3.2 (B), R12.2
unnamed: Q4.2 (B), R14.2
unnamed: Q5.2 (B), R16.2
unnamed: R9.1, U5.1
unnamed: R10.1, U5.3
unnamed: R11.1, U6.1
unnamed: R12.1, U6.3
unnamed: R13.1, U7.1
unnamed: R14.1, U7.3
unnamed: R15.1, U8.1
unnamed: R16.1, U8.3
unnamed: R2.1, USB1.4 (CC1)
unnamed: R3.1, USB1.10 (CC2)
VCC: F1.1, U3.4 (VCC), USB1.2 (VBUS), USB1.11 (VBUS)

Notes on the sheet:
Voltage Regulator 5V to 3.3V
4-Channel Relays
Relay-1
Relay-4
Relay-3
Relay-2
Auto-Reset
ESP32-WROOM-32
If DTR is LOW, toggling RTS from HIGH to LOW resets to run mode. If RTS is HIGH, toggling DTR from LOW to HIGH resets to bootloader.
USB To Serial Converter
Default
IO_2
IO_15 = MDTO
Bootloader
IO_0
IO_12 = MDTI
Run
Boot Mode Configuration
IO_5
Pin

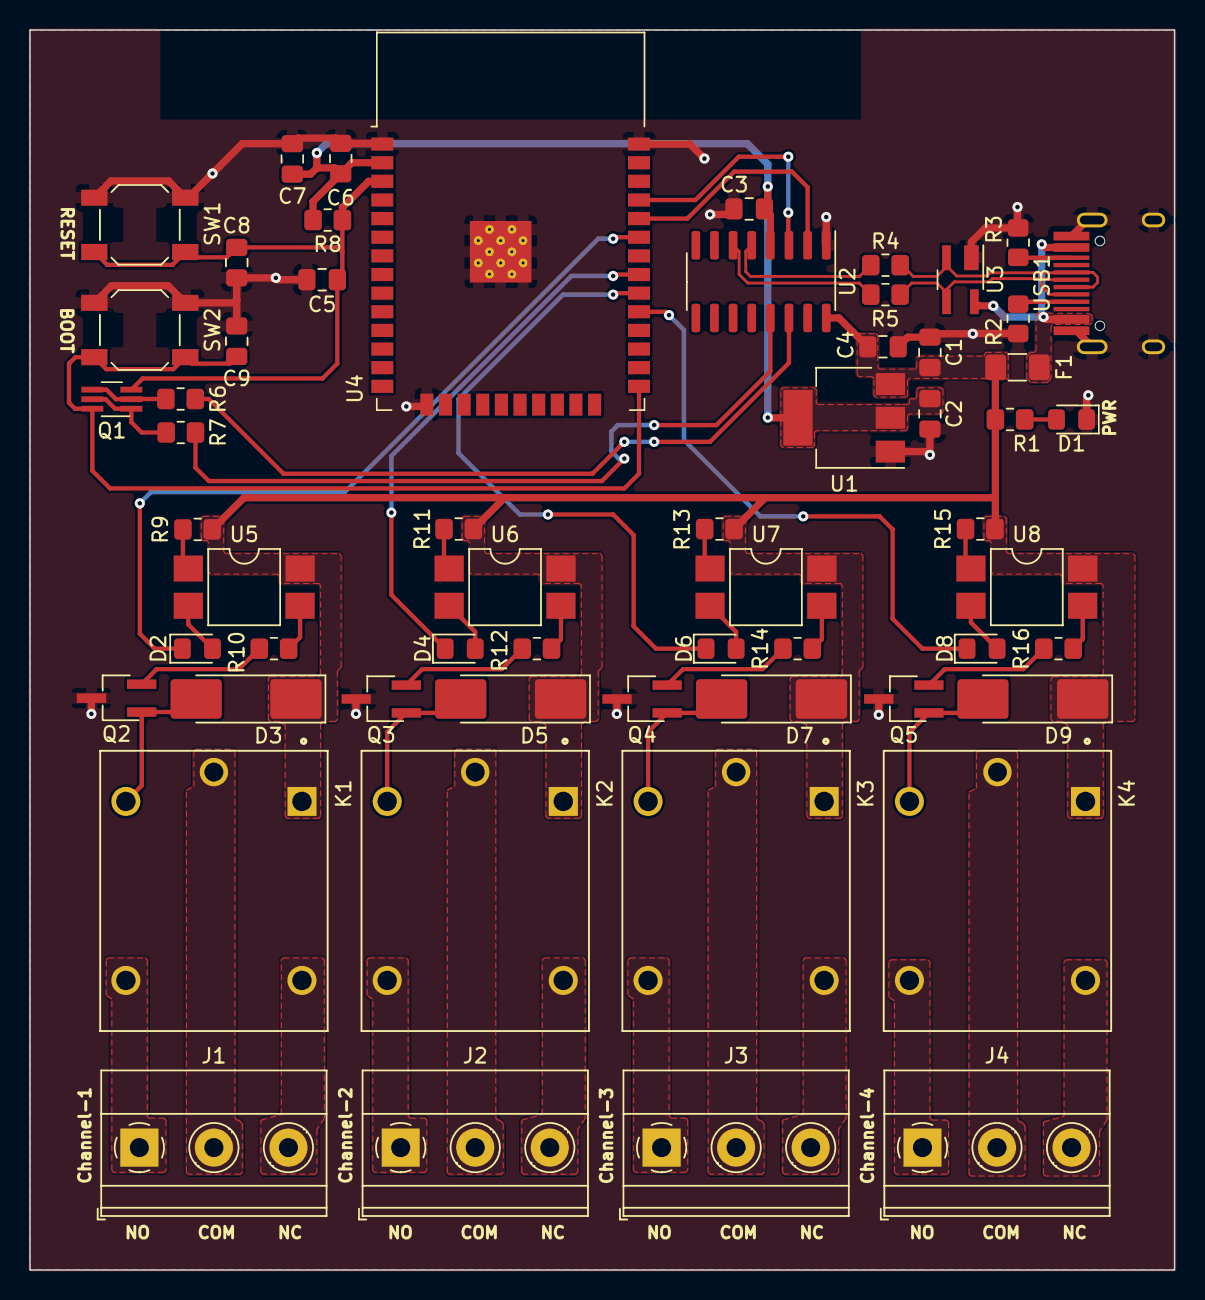
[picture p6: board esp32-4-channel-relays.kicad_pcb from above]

Board: 2 copper layers, 78.0 x 84.5 mm, 59 parts (0 on the bottom side), 55 nets.

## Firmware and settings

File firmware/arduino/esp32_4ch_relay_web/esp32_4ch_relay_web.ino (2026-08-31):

/**
 * @file esp32_4ch_relay_web.ino
 * @brief Professional Web & Serial Controller for ESP32 4-Channel Relay Board
 * @author Phan Huynh Van Do
 * 
 * Hardware Relay Mapping:
 * - Relay 1: GPIO 21
 * - Relay 2: GPIO 19
 * - Relay 3: GPIO 18
 * - Relay 4: GPIO 5
 */

#include <WiFi.h>
#include <WebServer.h>
#include <ESPmDNS.h>

// ==========================================
// CONFIGURATION
// ==========================================
const char* WIFI_SSID = "YOUR_WIFI_SSID";
const char* WIFI_PASS = "YOUR_WIFI_PASSWORD";
const char* HOSTNAME  = "esp32-relay";

// Pin Definitions
const uint8_t RELAY_PINS[4] = {21, 19, 18, 5};
bool relayStates[4] = {false, false, false, false};

WebServer server(80);

// ==========================================
// HTML / CSS WEB INTERFACE
// ==========================================
const char INDEX_HTML[] PROGMEM = R"rawliteral(
<!DOCTYPE html>
<html lang="en">
<head>
  <meta charset="UTF-8">
  <meta name="viewport" content="width=device-width, initial-scale=1.0">
  <title>ESP32 4-Channel Relay Controller</title>
  <style>
    :root {
      --bg: #0f172a;
      --card-bg: #1e293b;
      --accent: #38bdf8;
      --on-color: #22c55e;
      --off-color: #ef4444;
      --text: #f8fafc;
      --text-muted: #94a3b8;
    }
    * { box-sizing: border-box; margin: 0; padding: 0; font-family: -apple-system, BlinkMacSystemFont, "Segoe UI", Roboto, sans-serif; }
    body { background: var(--bg); color: var(--text); display: flex; flex-direction: column; align-items: center; min-height: 100vh; padding: 20px; }
    header { text-align: center; margin-bottom: 24px; }
    header h1 { font-size: 1.8rem; color: var(--accent); margin-bottom: 6px; }
    header p { color: var(--text-muted); font-size: 0.95rem; }
    .grid { display: grid; grid-template-columns: repeat(auto-fit, minmax(240px, 1fr)); gap: 18px; width: 100%; max-width: 720px; }
    .card { background: var(--card-bg); border-radius: 16px; padding: 20px; box-shadow: 0 10px 25px rgba(0,0,0,0.3); display: flex; flex-direction: column; align-items: center; transition: transform 0.2s, box-shadow 0.2s; border: 1px solid rgba(255,255,255,0.05); }
    .card:hover { transform: translateY(-3px); }
    .card-title { font-size: 1.2rem; font-weight: 600; margin-bottom: 6px; }
    .pin-info { font-size: 0.8rem; color: var(--text-muted); margin-bottom: 16px; }
    .indicator { width: 18px; height: 18px; border-radius: 50%; display: inline-block; margin-bottom: 16px; transition: background-color 0.3s; box-shadow: 0 0 10px rgba(0,0,0,0.5); }
    .btn { width: 100%; padding: 12px; border: none; border-radius: 10px; font-weight: bold; font-size: 1rem; cursor: pointer; color: white; transition: 0.2s; }
    .btn-on { background: var(--on-color); box-shadow: 0 4px 15px rgba(34, 197, 94, 0.4); }
    .btn-off { background: var(--off-color); box-shadow: 0 4px 15px rgba(239, 68, 68, 0.4); }
    .global-actions { margin-top: 24px; display: flex; gap: 14px; width: 100%; max-width: 720px; }
    .global-btn { flex: 1; padding: 14px; border: none; border-radius: 12px; font-size: 1rem; font-weight: 600; cursor: pointer; background: #334155; color: var(--text); transition: 0.2s; }
    .global-btn:hover { background: #475569; }
    footer { margin-top: 36px; font-size: 0.8rem; color: var(--text-muted); text-align: center; }
  </style>
</head>
<body>
  <header>
    <h1>⚡ ESP32 4-Channel Relay</h1>
    <p>Opto-Isolated IoT Power Control System</p>
  </header>

  <div class="grid" id="relays">
    <!-- Rendered via JavaScript -->
  </div>

  <div class="global-actions">
    <button class="global-btn" onclick="setAll(1)">Turn All ON</button>
    <button class="global-btn" onclick="setAll(0)">Turn All OFF</button>
  </div>

  <footer>
    Hardware Design by Phan Huỳnh Văn Đô • Built with ESP32 & KiCad
  </footer>

  <script>
    const pins = ["GPIO 21", "GPIO 19", "GPIO 18", "GPIO 5"];
    async function updateUI() {
      const res = await fetch('/api/status');
      const data = await res.json();
      const container = document.getElementById('relays');
      container.innerHTML = '';
      data.relays.forEach((state, i) => {
        const card = document.createElement('div');
        card.className = 'card';
        card.innerHTML = `
          <div class="card-title">Channel ${i + 1}</div>
          <div class="pin-info">${pins[i]}</div>
          <span class="indicator" style="background: ${state ? '#22c55e' : '#64748b'}; box-shadow: ${state ? '0 0 12px #22c55e' : 'none'};"></span>
          <button class="btn ${state ? 'btn-off' : 'btn-on'}" onclick="toggleRelay(${i + 1})">
            ${state ? 'Turn OFF' : 'Turn ON'}
          </button>
        `;
        container.appendChild(card);
      });
    }

    async function toggleRelay(ch) {
      await fetch(`/api/relay?ch=${ch}&state=toggle`);
      updateUI();
    }

    async function setAll(state) {
      await fetch(`/api/all?state=${state}`);
      updateUI();
    }

    setInterval(updateUI, 2500);
    updateUI();
  </script>
</body>
</html>
)rawliteral";

// ==========================================
// RELAY CONTROL FUNCTIONS
// ==========================================
void setRelay(uint8_t channel, bool state) {
  if (channel < 1 || channel > 4) return;
  relayStates[channel - 1] = state;
  digitalWrite(RELAY_PINS[channel - 1], state ? HIGH : LOW);
  Serial.printf("[RELAY] Channel %d set to %s (GPIO %d)\n", channel, state ? "ON" : "OFF", RELAY_PINS[channel - 1]);
}

void toggleRelay(uint8_t channel) {
  if (channel < 1 || channel > 4) return;
  setRelay(channel, !relayStates[channel - 1]);
}

// ==========================================
// REST API HANDLERS
// ==========================================
void handleRoot() {
  server.send_P(200, "text/html", INDEX_HTML);
}

void handleStatus() {
  String json = "{\"relays\":[";
  for (int i = 0; i < 4; i++) {
    json += relayStates[i] ? "true" : "false";
    if (i < 3) json += ",";
  }
  json += "]}";
  server.send(200, "application/json", json);
}

void handleRelay() {
  if (server.hasArg("ch")) {
    int ch = server.arg("ch").toInt();
    if (server.hasArg("state")) {
      String st = server.arg("state");
      if (st == "toggle") toggleRelay(ch);
      else if (st == "1" || st == "true" || st == "on") setRelay(ch, true);
      else setRelay(ch, false);
    }
  }
  handleStatus();
}

void handleAll() {
  if (server.hasArg("state")) {
    bool st = server.arg("state").toInt() == 1;
    for (int i = 1; i <= 4; i++) setRelay(i, st);
  }
  handleStatus();
}

// ==========================================
// SERIAL COMMAND PROCESSOR
// ==========================================
void processSerialCommand(String cmd) {
  cmd.trim();
  cmd.toUpperCase();
  if (cmd == "STATUS") {
    Serial.println("\n--- RELAY STATUS ---");
    for (int i = 0; i < 4; i++) {
      Serial.printf("Relay %d (GPIO %d): %s\n", i + 1, RELAY_PINS[i], relayStates[i] ? "ON" : "OFF");
    }
  } else if (cmd == "ALL ON") {
    for (int i = 1; i <= 4; i++) setRelay(i, true);
  } else if (cmd == "ALL OFF") {
    for (int i = 1; i <= 4; i++) setRelay(i, false);
  } else if (cmd.startsWith("R") || cmd.startsWith("RELAY")) {
    // E.g. "R1 ON" or "RELAY 2 OFF"
    int ch = cmd.charAt(cmd.indexOf(' ') - 1) - '0';
    if (ch >= 1 && ch <= 4) {
      if (cmd.endsWith("ON")) setRelay(ch, true);
      else if (cmd.endsWith("OFF")) setRelay(ch, false);
      else if (cmd.endsWith("TOGGLE")) toggleRelay(ch);
    }
  }
}

// ==========================================
// SETUP & LOOP
// ==========================================
void setup() {
  Serial.begin(115200);
  delay(500);
  Serial.println("\n==========================================");
  Serial.println(" ESP32 4-Channel Relay Controller Starting ");
  Serial.println("==========================================");

  // Initialize GPIOs
  for (int i = 0; i < 4; i++) {
    pinMode(RELAY_PINS[i], OUTPUT);
    digitalWrite(RELAY_PINS[i], LOW);
    relayStates[i] = false;
  }

  // Connect to WiFi
  WiFi.mode(WIFI_STA);
  WiFi.begin(WIFI_SSID, WIFI_PASS);
  Serial.print("Connecting to WiFi");
  int attempts = 0;
  while (WiFi.status() != WL_CONNECTED && attempts < 20) {
    delay(500);
    Serial.print(".");
    attempts++;
  }

  if (WiFi.status() == WL_CONNECTED) {
    Serial.println("\n[WiFi] Connected successfully!");
    Serial.print("[WiFi] IP Address: ");
    Serial.println(WiFi.localIP());

    if (MDNS.begin(HOSTNAME)) {
      Serial.printf("[mDNS] Responder started: http://%s.local\n", HOSTNAME);
    }
  } else {
    Serial.println("\n[WiFi] Connection failed. Starting Access Point mode...");
    WiFi.mode(WIFI_AP);
    WiFi.softAP("ESP32_4CH_RELAY_AP", "12345678");
    Serial.print("[AP] IP Address: ");
    Serial.println(WiFi.softAPIP());
  }

  // Setup WebServer Routes
  server.on("/", handleRoot);
  server.on("/api/status", handleStatus);
  server.on("/api/relay", handleRelay);
  server.on("/api/all", handleAll);
  server.begin();
  Serial.println("[HTTP] Web server started.");
}

void loop() {
  server.handleClient();

  if (Serial.available()) {
    String cmd = Serial.readStringUntil('\n');
    processSerialCommand(cmd);
  }
}

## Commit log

2026-08-31 feat: initial release of ESP32 4-channel opto-isolated relay controller
    [BOM.csv, esp32-4-channel-relays.kicad_pcb, esp32-4-channel-relays.kicad_sch]
2026-11-02 Replace old project with ESP32-C3 Mini 4-Channel Relay PCB
